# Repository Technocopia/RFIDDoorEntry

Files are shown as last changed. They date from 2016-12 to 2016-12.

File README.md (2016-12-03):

# RFIDDoorEntry
Esp8266/arduino powered keycard access system.

* NodeMCU for internet connectivity.
* Atmega8 to handle reader and door solenoid.
* Shared i2c EEPROM to store card info connected to NodeMCU
* 3mm audio jack for current transformer connected to node and atmega
* 7 GPIO
* 4 MOSFET solenoid drivers
* connects to any reader that can output wiegand data (we use a hid prox reader)

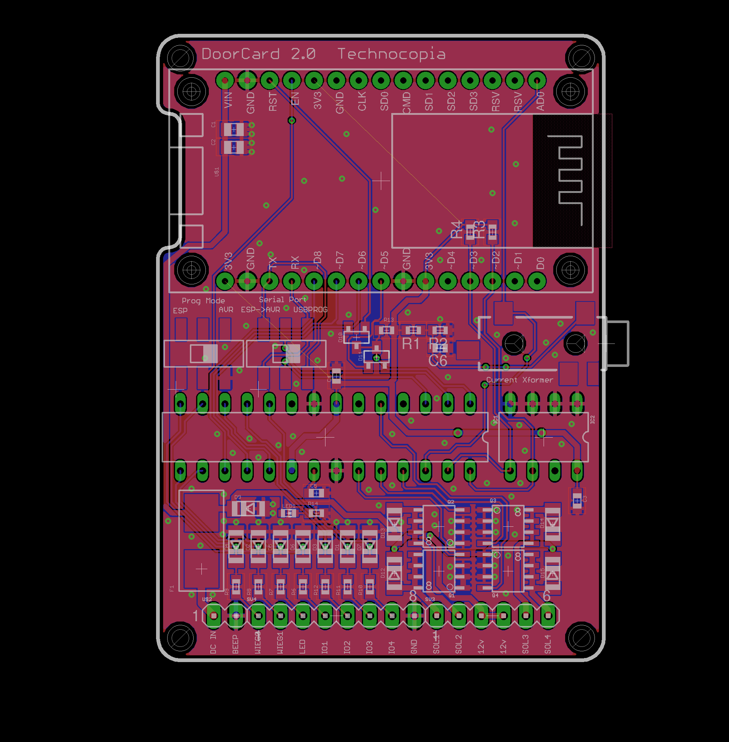
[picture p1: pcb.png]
pcb
 
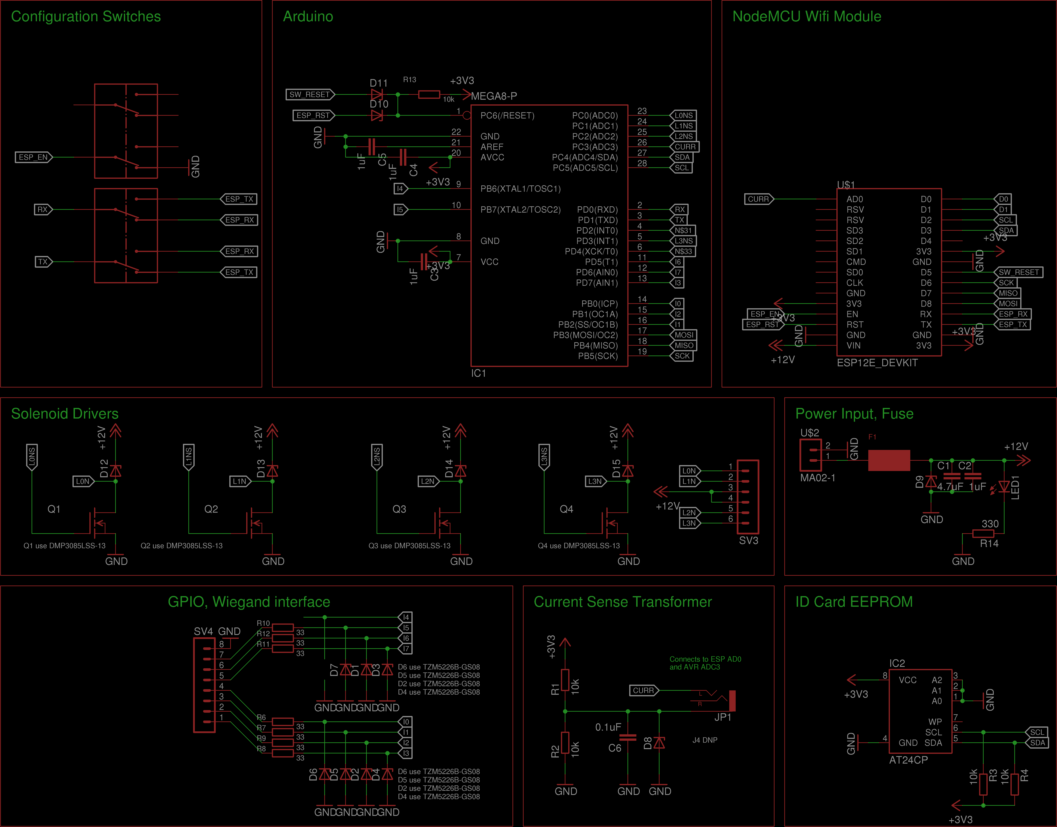
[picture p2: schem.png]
schematic


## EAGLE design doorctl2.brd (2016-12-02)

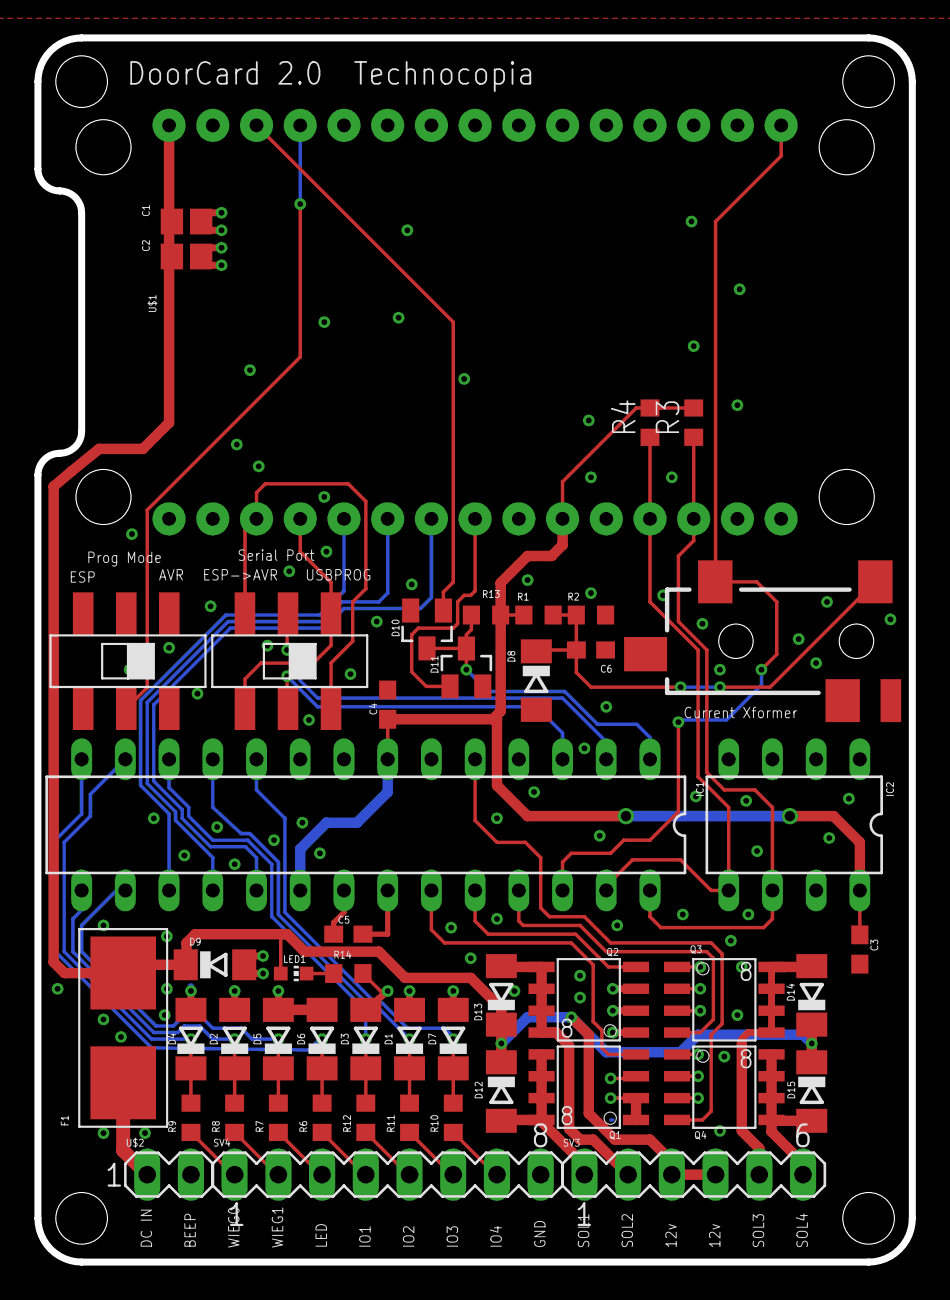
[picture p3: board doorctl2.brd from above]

Board: 2 copper layers, 50.8 x 71.1 mm, 49 parts (0 on the bottom side), 43 nets.

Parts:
C1: 4.7uF; C0805
C2: 1uF; C0805
C3, C4, C5: 1uF; C0603
C6: 0.1uF; C0603
D1, D2, D3, D4, D5, D6, D7, D8, D9, D12, D13, D14, D15: SOD80C
D10, D11: SOT23
F1: 0154
IC1: MEGA8-P; DIL28-3
IC2: AT24CP; DIL08
JP1: AUDIO-JACK-3.5MM-SMD
LED1: CHIP-LED0603
Q1, Q2, Q3, Q4: FDS5680; SO-8
R1, R2, R3, R4, R13: 10k; R0603
R6, R7, R8, R9, R10, R11, R12: 33; R0603
R14: 330; R0603
SV3: MA06-1
SV4: MA08-1
SW1, SW2: L202011MS02Q; SMT
U$1: ESP12E_DEVKIT
U$2: MA02-1

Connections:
+3V3: C3.1, C4.1, IC1.7, IC1.20, IC2.8, R1.2, R3.2, R4.2, R13.2, U$1.3V3@0, U$1.3V3@1, U$1.3V3@2
+12V: C1.1, C2.1, D9.C, D12.C, D13.C, D14.C, D15.C, F1.2, LED1.A, SV3.3, SV3.4, U$1.VIN
AVR_RST: D10.3, D11.3, IC1.1, R13.1
CURR: IC1.26, JP1.TIP, U$1.AD0
ESP_EN: SW1.A, U$1.EN
ESP_RST: D10.1, U$1.RST
ESP_RX: SW2.A1, SW2.B2, U$1.RX
ESP_TX: SW2.A2, SW2.B1, U$1.TX
GND: C1.2, C2.2, C3.2, C4.2, C5.2, C6.1, D1.A, D2.A, D3.A, D4.A, D5.A, D6.A, D7.A, D8.A, D9.A, IC1.8, IC1.22, IC2.1, IC2.2, IC2.3, IC2.4, Q1.1, Q1.2, Q1.3, Q2.1, Q2.2, Q2.3, Q3.1, Q3.2, Q3.3, Q4.1, Q4.2, Q4.3, R2.1, R14.2, SV4.8, SW1.A2, U$1.GND@1, U$1.GND@2, U$1.GND@3, U$2.2
I0: D6.C, IC1.14, R6.2
I1: D5.C, IC1.16, R7.2
I2: D2.C, IC1.15, R8.2
I3: D4.C, IC1.13, R9.2
I5: D7.C, IC1.10, R10.2
I6: D1.C, IC1.11, R11.2
I7: D3.C, IC1.12, R12.2
L0N: D12.A, Q1.5, Q1.6, Q1.7, Q1.8, SV3.1
L0NS: IC1.23, Q1.4
L1N: D13.A, Q2.5, Q2.6, Q2.7, Q2.8, SV3.2
L1NS: IC1.24, Q2.4
L2N: D14.A, Q3.5, Q3.6, Q3.7, Q3.8, SV3.5
L2NS: IC1.25, Q3.4
L3N: D15.A, Q4.5, Q4.6, Q4.7, Q4.8, SV3.6
L3NS: IC1.5, Q4.4
MISO: IC1.18, U$1.D7
MOSI: IC1.17, U$1.D8
unnamed: R6.1, SV4.4
unnamed: R7.1, SV4.3
unnamed: R8.1, SV4.2
unnamed: R9.1, SV4.1
unnamed: C6.2, D8.C, JP1.SLEEVE, R1.1, R2.2
unnamed: R10.1, SV4.7
unnamed: R11.1, SV4.6
unnamed: R12.1, SV4.5
unnamed: F1.1, U$2.1
unnamed: C5.1, IC1.21
unnamed: LED1.C, R14.1
RX: IC1.2, SW2.B
SCK: IC1.19, U$1.D6
SCL: IC1.28, IC2.6, R3.1, U$1.D2
SDA: IC1.27, IC2.5, R4.1, U$1.D3
SW_RESET: D11.1, U$1.D5
TX: IC1.3, SW2.A

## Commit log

2016-12-02 PCB done
    [doorctl2.brd, doorctl2.sch]
2016-12-02 board img
2016-12-02 Added Zener to sense xformer input
    [doorctl2.brd]
2016-12-03 cleaned iup schem, added zener
    [doorctl2.sch]

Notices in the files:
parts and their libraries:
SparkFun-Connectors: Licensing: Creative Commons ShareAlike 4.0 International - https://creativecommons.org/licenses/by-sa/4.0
